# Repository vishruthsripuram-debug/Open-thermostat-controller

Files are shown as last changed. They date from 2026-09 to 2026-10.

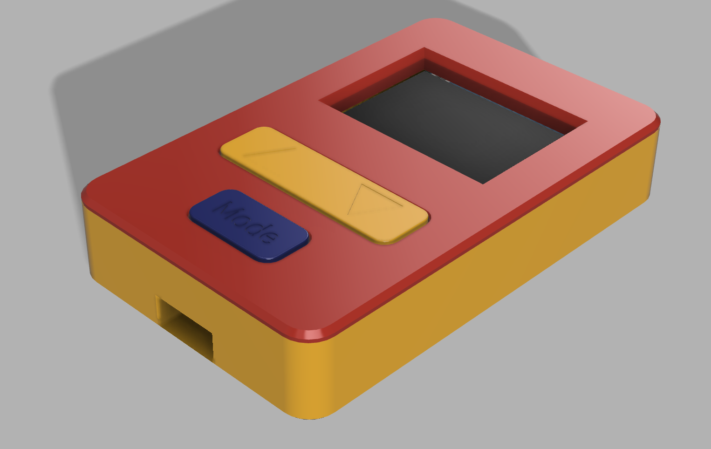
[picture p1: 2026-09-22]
Photos/Render.png

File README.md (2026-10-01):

# Open-thermostat-controller
A small thermostat controller for split units and zones with adaptable temperatures able to be used within home assistant.

## About
The open thermostat controller is a project designed to replace my old air conditioner remote, my old air conditioner remote was extremely large, clunky and ultimately a large wastof space in my bedroom, not to mention it looked incredibly ugly. I designed my device to be small, compact and useful featuring a simple 3 button layout that simplifies the old large remote into a smaller much more elegant design that can be placed on a desk or sat next to my pillow on my bed without any worries. The actual remote itself is a low power device simply communicating over thread with home assistant, using esphome, it controls the aircon using the integration built in with home assistant. 

## Instructions
### Assembly
1. Fabricate the PCB and 3D print the case.
2. Assemble the PCB by following the instructions printed onto the silkscreen, placing the selected components on their respective pads. Or order the PCB with assembly, for self assembly, an SMD stencil is preffered.
3. Place the buttons covers onto the buttons of the PCB, and insert the PCB into the case, use the screw holes from the display and screw the PCB into place.
4. Place down the top cover and press it into place, you should hear a faint click here.
5. You're finished, now its time to flash
### Flashing
1. Plug the device into your computer using a usb c cable and download the ESPhome yaml from the repository.
2. upload the YAML and press the flash button on your screen, once the flash is completed a message will show up on the display as 'done flashing' and then configure the device in home assistant.
3. You're finished, you are now ready to use your device.

## CAD rendering
Screenshot 2026-09-22 at 2 34 57 PM

## PCB and schematic
Screenshot 2026-10-01 at 11 23 04 AM
Screenshot 2026-10-01 at 11 22 33 AM

## Design
Screenshot 2026-09-10 at 7 07 42 PM
Screenshot 2026-09-10 at 7 07 46 PM

## BOM
| Ref | Qty | Value | MPN | Supplier | Unit Price (USD) | Line Total (USD) | Buy Link |
|---|---|---|---|---|---|---|---|
| J1 | 1 | Conn_01x02_Socket (JST PH 2-pin, SMD side entry) | S2B-PH-SM4-TB(LF)(SN) | Digi-Key | $0.49 | $0.49 | [Buy](https://www.digikey.com/en/products/detail/jst-sales-america-inc/S2B-PH-SM4-TB/926655) |
| SW1, SW2, SW3 | 3 | SW_Push (SMD tactile) | PTS645SM43SMTR92 LFS | Digi-Key | $0.36 | $1.08 | [Buy](https://www.digikey.com/en/products/detail/c-k/PTS645SM43SMTR92-LFS/1146840) |
| U1 | 1 | XIAO-ESP32-C6-SMD | 113991254 | Digi-Key | $5.38 | $5.38 | [Buy](https://www.digikey.com/en/products/base-product/seeed-technology-co-ltd/1597/ESP32-C6/678377) |
| U2 | 1 | ER_OLEDM0.91_1x-I2C | ER-OLEDM0.91-1W-I2C | BuyDisplay | $2.80 | $2.80 | [Buy](https://www.buydisplay.com/i2c-white-0-91-inch-oled-display-module-128x32-arduino-raspberry-pi) |
| PCB | 1 | Custom PCB | - | - | $1.80 | $1.80 | - |
| | | | | | **Total** | **$11.55** | |

## Credits
Made entirely By vishruth
AI disclosure: The code for this project was written mostly by AI but nothing else was, all cad, PCB design and research was done by me.

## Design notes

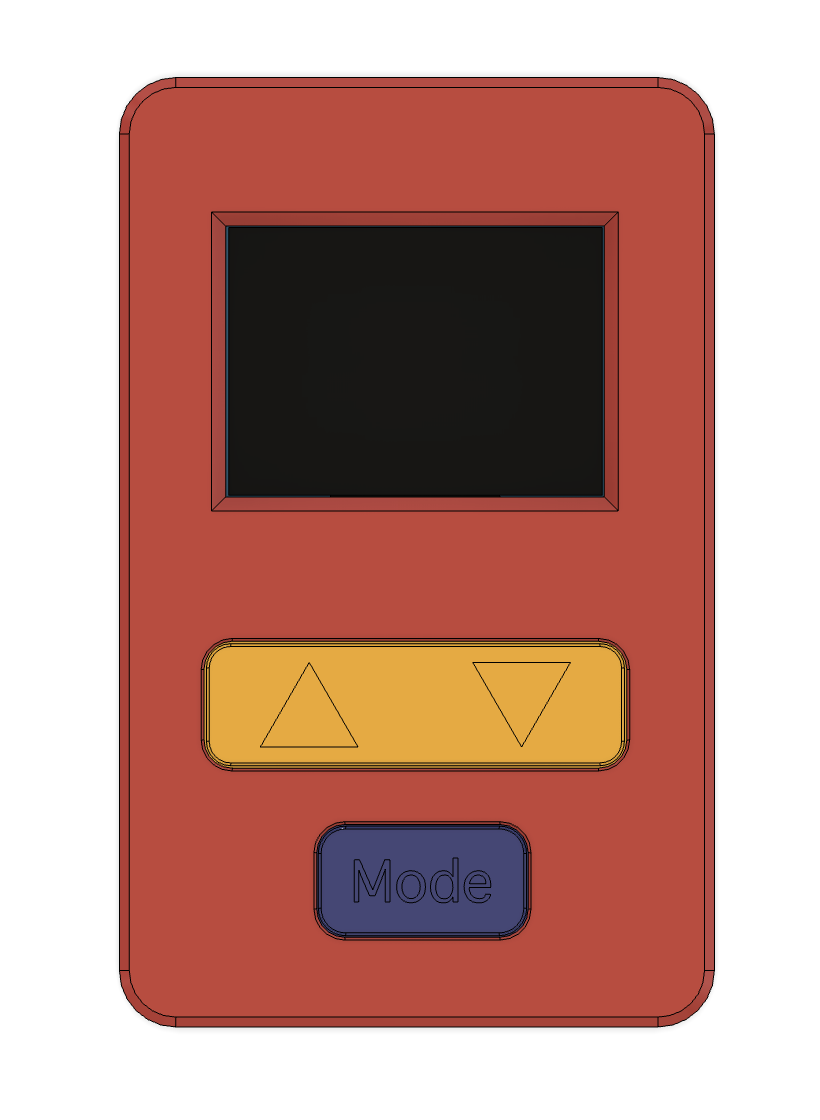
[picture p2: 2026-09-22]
Photos/top profile.png

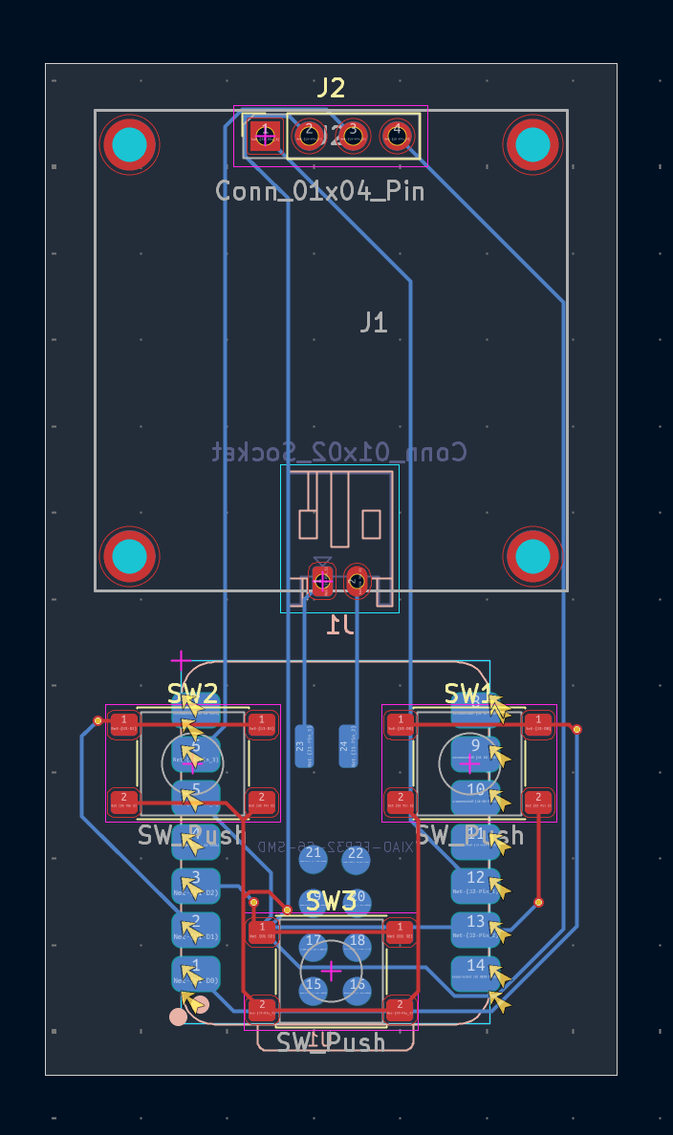
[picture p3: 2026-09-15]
Photos/Screenshot 2026-09-14 at 3.03.38 PM.png

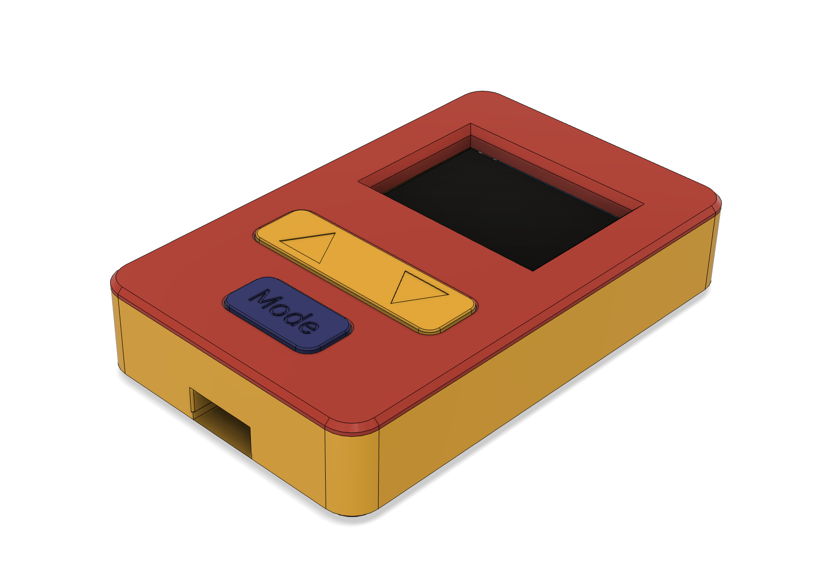
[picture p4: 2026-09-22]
Photos/Side profile.png

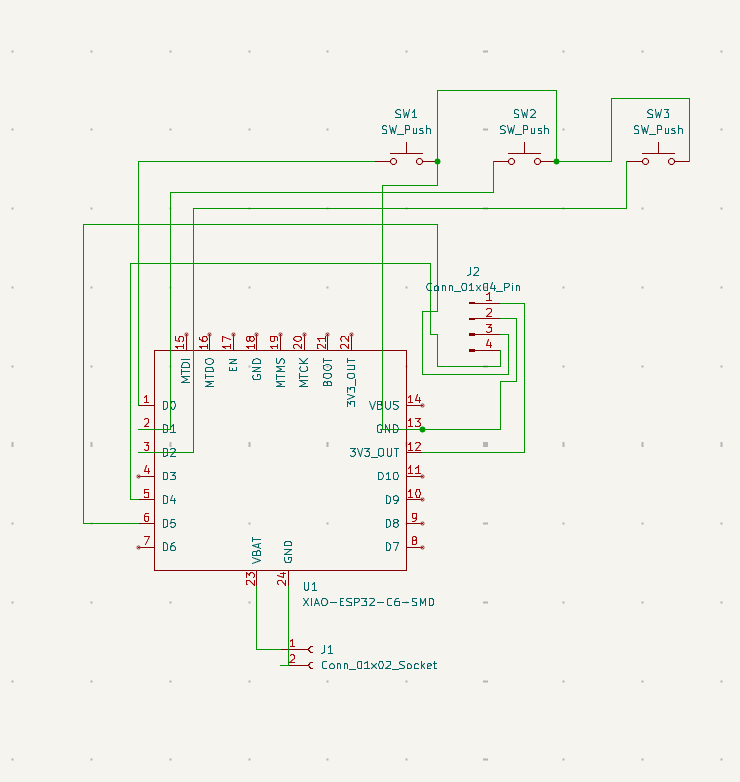
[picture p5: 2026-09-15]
Photos/Screenshot 2026-09-15 at 11.31.54 AM.png

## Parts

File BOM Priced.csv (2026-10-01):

Ref | Qty | Value | MPN | Supplier | Unit Price (USD) | Line Total (USD) | Buy Link | Notes
J1 | 1 | Conn_01x02_Socket (JST PH 2-pin, SMD side entry) | S2B-PH-SM4-TB(LF)(SN) | Digi-Key | 0.49 | 0.49 | https://www.digikey.com/en/products/detail/jst-sales-america-inc/S2B-PH-SM4-TB/926655 | Mouser also stocks it (306-S2BPHSM4TBLFSN, $0.49 @1). Part is a header; mates with a PHR-2 housing
SW1,SW2,SW3 | 3 | SW_Push (SMD tactile) | PTS645SM43SMTR92 LFS | Digi-Key | 0.36 | 1.08 | https://www.digikey.com/en/products/detail/c-k/PTS645SM43SMTR92-LFS/1146840 | Price breaks: $0.313 @10, $0.262 @100
U1 | 1 | XIAO-ESP32-C6-SMD | 113991254 | Digi-Key | 5.38 | 5.38 | https://www.digikey.com/en/products/base-product/seeed-technology-co-ltd/1597/ESP32-C6/678377 | Seeed XIAO ESP32-C6; Mouser lists it at $5.38 too. Seeed direct: $5.20 @10+
U2 | 1 | ER_OLEDM0.91_1x-I2C | ER-OLEDM0.91-1W-I2C | BuyDisplay | 2.8 | 2.8 | https://www.buydisplay.com/i2c-white-0-91-inch-oled-display-module-128x32-arduino-raspberry-pi | 0.91in 128x32 SSD1306 I2C (white); blue variant same price. Footprint in KiCad says 0.96in, check it matches
PCB | 1 | Custom PCB | - | (your quote) | 1.8 | 1.8 |  | Price as given by you, per PCB
 |  |  |  |  | Total | 11.55

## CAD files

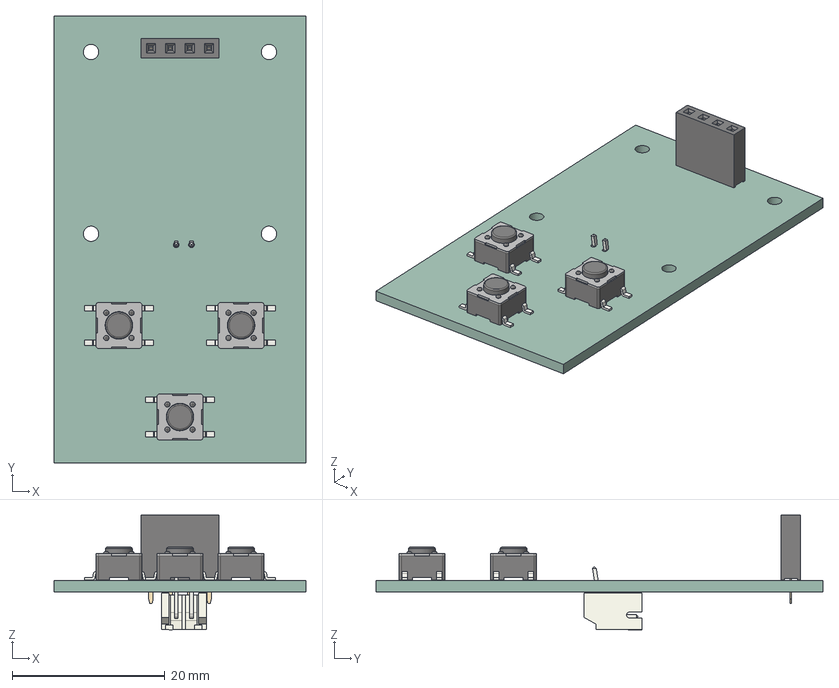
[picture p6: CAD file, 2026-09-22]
PCB Files remote/Ac controller.step
33.0 x 58.5 x 15.0 mm
SW_SPST_PTS645Sx43SMTR92 x 3
PinSocket_1x04_P2.54mm_Vertical
JST_S2B_PH_K
Ac controller-unsaved-export-HwYVHW_PCB

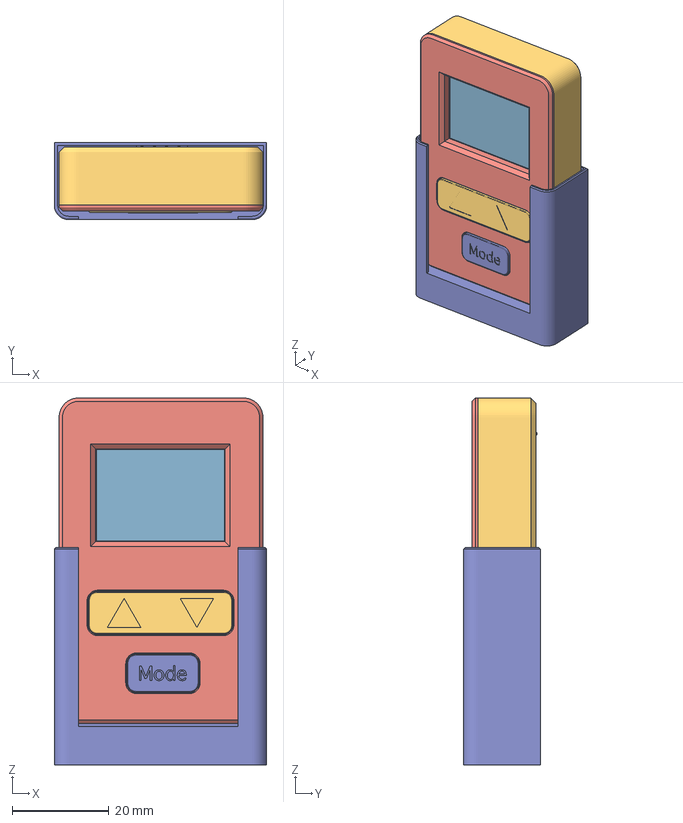
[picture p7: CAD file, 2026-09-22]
Remote CAD and print files/Ac controller holder.3mf
44.0 x 16.0 x 76.0 mm

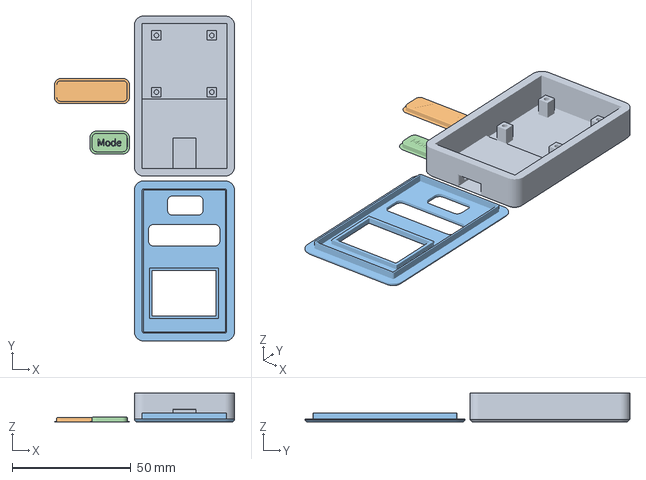
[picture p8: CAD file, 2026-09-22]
Remote CAD and print files/Ac controller mini print.3mf
75.8 x 136.7 x 12.0 mm

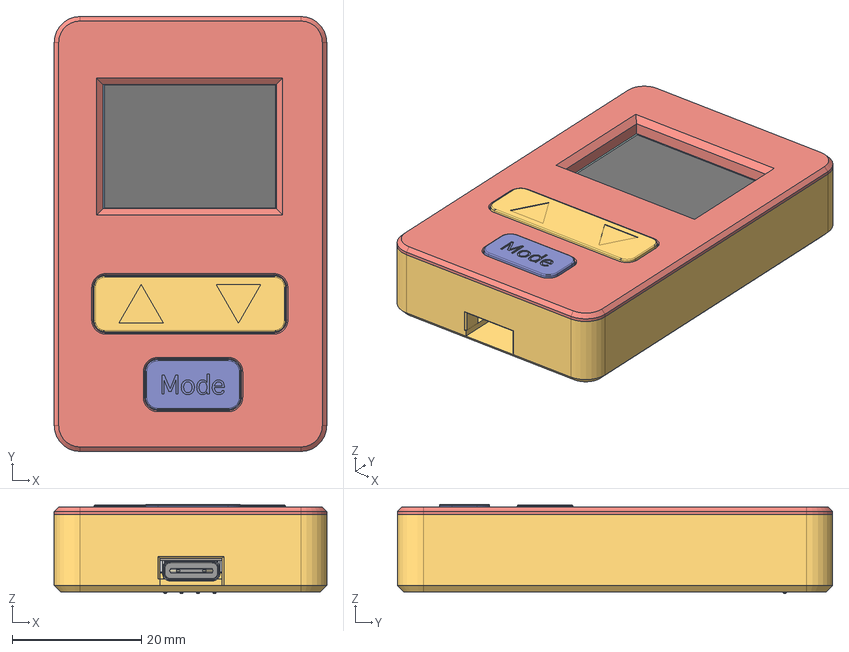
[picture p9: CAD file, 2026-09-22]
Remote CAD and print files/Ac controller mini.step
42.2 x 67.4 x 13.9 mm
SW_SPST_PTS645Sx43SMTR92_1 x 3
0.96" OLED v3
BOSS-EXTRUDE14_8_
BOSS-EXTRUDE7_4_
BOSS-EXTRUDE7_3_
BOSS-EXTRUDE14_4_
BOSS-EXTRUDE14_2_
BOSS-EXTRUDE14_11_
BOSS-EXTRUDE7_7_
BOSS-EXTRUDE14_9_
BOSS-EXTRUDE14_3_
BOSS-EXTRUDE14_7_
MIRROR2
BOSS-EXTRUDE14_5_
BOSS-EXTRUDE14_12_
BOSS-EXTRUDE7_8_
BOSS-EXTRUDE7_1_
BOSS-EXTRUDE14_10_
BOSS-EXTRUDE7_9_
BOSS-EXTRUDE14_6_
BOSS-EXTRUDE14_1_
BOSS-EXTRUDE7_6_
BOSS-EXTRUDE7_2_
CUT-EXTRUDE5
BOSS-EXTRUDE7_5_
U.FL Connector v1
Button (1) x 2
Shield
Ac controller_PCB
Lid
button

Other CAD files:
Remote CAD and print files/Ac controller holder.f3z
Remote CAD and print files/Ac controller mini.3mf
Remote CAD and print files/Ac controller mini.f3z

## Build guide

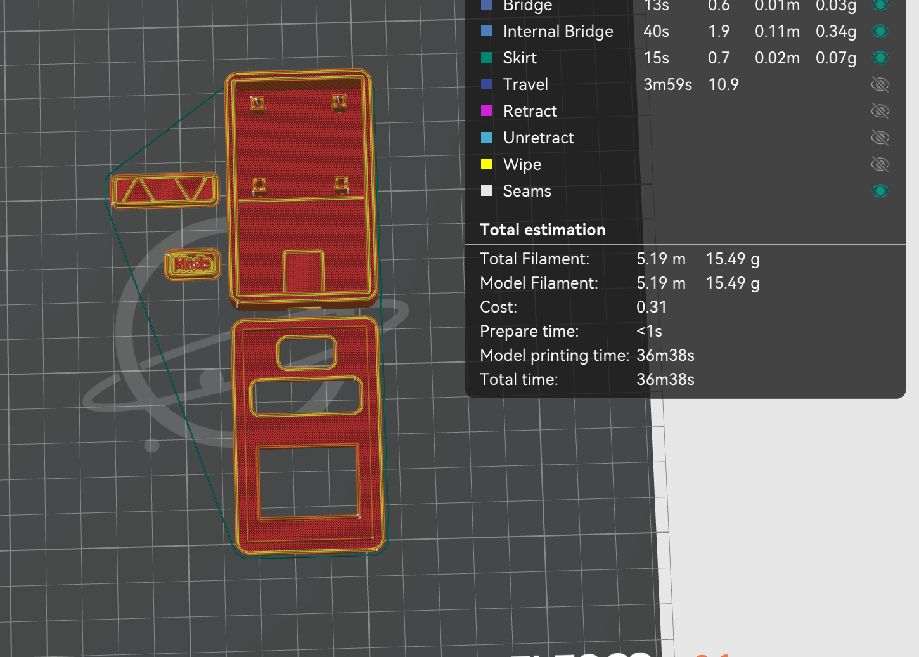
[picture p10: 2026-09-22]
Photos/3D print.png

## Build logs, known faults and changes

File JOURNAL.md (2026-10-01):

---
title: "Open thermostat"
author: "Vishruth S"
description: "A small controller for air conditioners in home assistant"
created_at: "2026-09-10"
---

# September 10: Designed the product
In canva i experimented with different screen layouts, colour choices and designs before finally landing on a design that had a main wall controller similar to the actron air neo.
I made 2 designs one for the large multifunction controller likely to be mounted to a wall and the small remote, the remote can change between devices such as hvac, space heater fan or mini split and works off of espnow from the wall controller. This connects to the central hub powered by espnow and plugged in for maximum battery life. I went through many iterations of the screen layout and buttons layout and colour themes and eventually landed on what is in my opinion the best looking version with the black backgrounds, black and white oled displays for cost savings and simple buttons which may be touch capacitive later.

I designed everything in canva white baord using simple shapes. this is what is now the basis for the design and it is what the final result will hopefully look like. I hope i can make them thin enough where they dont feel super heavy or thick.

Screenshot 2026-09-10 at 7 04 47 PM

**Total time spent: 3.5 hours**

# September 12: Research
I researched on what components to use, for the small remote i decided on using simple buttons because trying to use capacitive buttons in the middle of the night would not be super pleasant and they do not offer any real benefits anyway. I chose to do the same with the larger room controller and opted to use a 2.4" monochrome OLED with normal push button switches for a more tactile feel. The displays can be purchased cheaply from Aliexpress and offer all of the functionality needed for the project such as showing temperature, being bright, having adjustable temperatures and most importantly having a low load on the esp32 for maximum power efficiency as these are both battery powered devices, with the option of a dock for charging. For the dock, i was planning on having a simple barebones style and thick heavy style of dock for the remote and having a magnetic dock for the larger main node, the magnets embedded in the back of the enclosure would adhere to a base station stand similar to that of one that the Actron Air Neo zone controller uses. The device will use a PCB to maintain a compact form factor and a Single-Cell 3.7V LiPo Pouch which is about 5mm thick to maintain a thin feel while also providing excellent battery life.

Screenshot 2026-09-13 at 11 42 46 PM
Screenshot 2026-09-13 at 11 42 32 PM

**Total time spent: 4.5 hours**

# September 14: PCB design
I started with the PCB design on Kicad, already having designed a macropad i had some sense of what to do, The first step was relatively straightforward i would add my 3 buttons, the screen and the board to my schematic an connect up all the wires. The first problem started when i tried to assign footprints to the symbols. When i tried to search for a 4 pin oled I2C display i incurred a serious hurdle as there was none that existed that fit what i was using. Instead i downloaded the KiCAD Mod File and imported it into KiCAD and then i had the display. After adding everything to the schematic i assigned all of the footprints and then moved to the pcb design workspace where i 
built the PCB I routed my traces correctly and used Via's to bring up the back copper face lines to the front. I added a battery conenctor for high power and long battery life when connected to a Lipo battery and easy charging capability when inserted into the dock. The PCB is one of my most complicated PCB's i have designed so far requiring SMD buttons and boards.

Screenshot 2026-09-15 at 11 22 10 AM
Screenshot 2026-09-15 at 11 22 27 AM

**Total time spent: 6 hours**

# September 17: CAD design
I ran into multiple issues with the CAD. When exporting from Kicad i had to manually edit the footprints to include the 3d models and edit the footprints. After that it was very simple. I inserted the PCB into fusion and designed a case to ecase the PCB. I designed it very simple and to be easily rechargeable. all you have to do is remove the pcb every 2-3 months or print the version with a built in charging port. The cad process was extremely simple until i got to the lid. I designed the lid to be held in place with screws and to have only 2 visible buttons the top button would be a rocker switch while the bottom would be a single button for mode cycling and power. figuring out the rocker switch was relatively was relatively easy and only took about 20 minutes to implement. 

Screenshot 2026-09-16 at 10 43 17 AM

**Total time spent: 3.5 hours**

# September 22: Mounting pegs and small fixes
I added 2 things to this revision, I Added the mounting pegs for the PCB so that the board sits stable when the buttons are being pressed and when the remote is being held, it also offers a solid platform for the device. The mounting pegs were simple i created a sketch on the PCB base and extruded through as a solid object and made the pillars around it. The second fix was reducing the height of the baseplate so that the seeed ESP32 C6 would fit nicely. There wasn't much to this revision it was mostly just bugfixing and updating the design, all of the new cad files have been uploaded as well as the new render of the device in an interesting colour selection inspired by the craighill scissors which i saw on YT shorts.

Screenshot 2026-09-22 at 2 51 53 PM
Screenshot 2026-09-22 at 2 51 38 PM

**Total time spent: 2.5 hours**

# September 23: designing schematic for Wall controller
For the schematic i decided on a simple layout similarly to the smaller device, the wall controller is always powered so there is no need for a battery, this wall controller has a 1.3" Adafruit OLED, which is slightly larger i found that increasing the size anymore would significantly impact the device or make it not worth the cost to spend and install when premade thermostat solutions already exist. For my particular use case i have chosen to use a 3.5" TFT display as i already have one and think it would look nice inside the display, the wall controlelr is relatively simple and i plan to even just split up the buttons onto a pcb and hand solder everything else using wires to keep the footprint to a minimum and to minimise pick and place components to make it more DIY accessible.

Screenshot 2026-09-23 at 5 45 53 PM

**Total time spent: 4 hours**

# October 1: scrapping the wall controller
I ultimately came to the conclusion that the wall controller was unnecessarily complex and ultimately quite useless considering the remote existed, however i still needed a way to control all of the smart devices in the room and act as the wall controller, i found the seeed studio sticky, this device can act a smart home dashboard and has buttons, since it is also esp based i can simply use espnow protocol to increase the battery life of the wall controller.


**Total time spent: 0.2 hours**

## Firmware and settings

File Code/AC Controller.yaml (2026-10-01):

substitutions:
  temp_step: "1"    # degrees per press (AC)
  fan_step: "10"    # percent per press (fan)

esphome:
  name: ac-controller
  friendly_name: AC Controller
  on_boot:
    priority: -100
    then:
      - lambda: |-
          std::string e[3] = {id(ent_1).state, id(ent_2).state, id(ent_3).state};
          std::string t[3] = {id(type_1).state, id(type_2).state, id(type_3).state};
          std::string m[3] = {id(modes_1).state, id(modes_2).state, id(modes_3).state};
          id(vals).assign(15, "");
          id(ents).assign(3, "");
          id(mode_lists).assign(3, "");
          id(types).assign(3, 0);
          for (int i = 0; i < 3; i++) {
            if (e[i].empty()) continue;
            int base = i * 5;
            id(ents)[i] = e[i];
            id(mode_lists)[i] = m[i];
            id(types)[i] = (t[i] == "Fan") ? 2 : 1;
            api::global_api_server->subscribe_home_assistant_state(e[i], optional<std::string>(),
              [base](const std::string &s) { id(vals)[base] = s; });
            if (id(types)[i] == 1) {
              api::global_api_server->subscribe_home_assistant_state(e[i], optional<std::string>("temperature"),
                [base](const std::string &s) { id(vals)[base + 1] = s; });
              api::global_api_server->subscribe_home_assistant_state(e[i], optional<std::string>("current_temperature"),
                [base](const std::string &s) { id(vals)[base + 2] = s; });
            } else {
              api::global_api_server->subscribe_home_assistant_state(e[i], optional<std::string>("percentage"),
                [base](const std::string &s) { id(vals)[base + 3] = s; });
              api::global_api_server->subscribe_home_assistant_state(e[i], optional<std::string>("preset_mode"),
                [base](const std::string &s) { id(vals)[base + 4] = s; });
            }
          }
          if (id(types)[id(dev)] == 0) {
            for (int i = 0; i < 3; i++) if (id(types)[i] != 0) { id(dev) = i; break; }
          }
      - delay: 5s
      - lambda: 'id(show_boot) = false;'

esp32:
  board: esp32-c6-devkitc-1
  variant: esp32c6
  framework:
    type: esp-idf

logger:

network:
  enable_ipv6: true

openthread:
  tlv: !secret thread_dataset_tlv

api:
  encryption:
    key: !secret api_key

ota:
  - platform: esphome
    password: !secret ota_password

i2c:
  sda: GPIO22   # D4
  scl: GPIO23   # D5
  frequency: 400kHz

font:
  - file: "gfonts://Roboto"
    id: font_small
    size: 12
  - file: "gfonts://Roboto"
    id: font_big
    size: 20

globals:
  - id: dev                 # active device slot, remembered across reboots
    type: int
    restore_value: yes
    initial_value: "0"
  - id: next_dev
    type: int
    initial_value: "0"
  - id: show_boot
    type: bool
    initial_value: "true"
  - id: msg_until
    type: uint32_t
    initial_value: "0"
  - id: msg
    type: std::string
  - id: cur_entity
    type: std::string
  - id: cur_arg
    type: std::string
  - id: cur_kind            # 0 none, 1 climate, 2 fan
    type: int
    initial_value: "0"
  - id: vals                # 5 values per slot: state, temp, current temp, percentage, preset
    type: std::vector<std::string>
  - id: ents
    type: std::vector<std::string>
  - id: mode_lists
    type: std::vector<std::string>
  - id: types
    type: std::vector<int>

# ---------- Configuration interface (shows in HA under the device's Configuration) ----------
text:
  - platform: template
    name: "Device 1 Entity"
    id: ent_1
    mode: text
    optimistic: true
    restore_value: true
    initial_value: "climate.bedroom_ac"
    max_length: 64
    entity_category: config
  - platform: template
    name: "Device 1 Modes"
    id: modes_1
    mode: text
    optimistic: true
    restore_value: true
    initial_value: "cool,heat,dry,fan_only,auto"
    max_length: 64
    entity_category: config
  - platform: template
    name: "Device 2 Entity"
    id: ent_2
    mode: text
    optimistic: true
    restore_value: true
    initial_value: "fan.dyson_purifier"
    max_length: 64
    entity_category: config
  - platform: template
    name: "Device 2 Modes"
    id: modes_2
    mode: text
    optimistic: true
    restore_value: true
    initial_value: "Auto,Manual"
    max_length: 64
    entity_category: config
  - platform: template
    name: "Device 3 Entity"
    id: ent_3
    mode: text
    optimistic: true
    restore_value: true
    initial_value: ""
    max_length: 64
    entity_category: config
  - platform: template
    name: "Device 3 Modes"
    id: modes_3
    mode: text
    optimistic: true
    restore_value: true
    initial_value: "cool,heat,dry,fan_only,auto"
    max_length: 64
    entity_category: config
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

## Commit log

2026-09-13 Update JOURNAL with research on remote components
    Documented research on components for remote and room controller, including button selection and display options for power efficiency.
2026-09-13 Document component choices and design for controllers
    Added details about component choices and design considerations for the remote and room controller, including display and power efficiency.
2026-09-15 Enhance PCB design entry with detailed process description
    Expanded the PCB design section with additional details about the design process, including challenges faced and features added.
2026-09-19 Document CAD design process and challenges
    Added details about CAD design process and issues encountered.
2026-09-22 Create print
2026-10-01 Create gerber file
2026-10-01 Modify PCB section and remove schematic header
    Updated section headers for PCB and schematic.
2026-10-01 Update README with assembly and flashing instructions
    Added assembly and flashing instructions for the device.
